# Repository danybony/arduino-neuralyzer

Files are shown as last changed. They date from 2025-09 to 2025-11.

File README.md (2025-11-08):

# Arduino-Android Neuralyzer
A Men in Black Neuralyzer made with Arduino and controlled by an Android app.

Presented at [DevFest Pescara 2025](https://devfest.gdgpescara.it/it/).

https://github.com/user-attachments/assets/2ab9053a-5b03-4355-8828-ae3a430f30dd

## 3D printing
The neuralyzer can be easily 3d printed. All the related info are in [the dedicated document](3D_model/README.md).

## Bill Of Material

- Arduino Nano 33 BLE https://store.arduino.cc/products/arduino-nano-33-ble 

- Arduino Nano Connector Carrier https://store.arduino.cc/products/nano-connector-carrier

- Modulino Pixels https://store.arduino.cc/products/modulino-pixels

- Modulino Buttons https://store.arduino.cc/products/modulino-buttons
  
- 9V PP3 battery 

- 9V PP3 battery connector https://amzn.to/47Poghs 

## Slide Deck

[Presentation here](https://docs.google.com/presentation/d/1N28yC9nN8kCC65EGHAueS5vN4FuV5YYNEZBnSAGI6ws/edit?usp=sharing)

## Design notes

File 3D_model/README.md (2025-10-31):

# Arduino-Android Neuralyzer 3D model
The 3D model for the neuralyzer is composed of the following parts, each one with the relative .stl print file:

- **Bottom enclosure**: the base of the model, contains the battery and the Arduino
- **Top enclosure**: the upper part of the model, contains the Modulino modules, and the trigger button
- **Button**: the trigger button, aligned with the central Modulino button
- **Top sphere**: the dome at the top of the model
- **Modulino beds**: internal support for the two Modulinos. They are marked with L for the LED Modulino, B for the buttons Modulino. They slide inside the top enclosure

## Print configuration

- Filament: PLA
- Layers height: 0.20 mm
- Infil: 25%
- Brim: optional
- Support: everywhere, organic. Only needed for the top enclosure.

## Asssembly

1. Place each Modulino to the relative supporting bed: the one marked with L for the LED one, B for the button one
2. Connect the two Modulinos together with their ribbon cable, making it pass through the supporting beds central hole, like in the following picture:

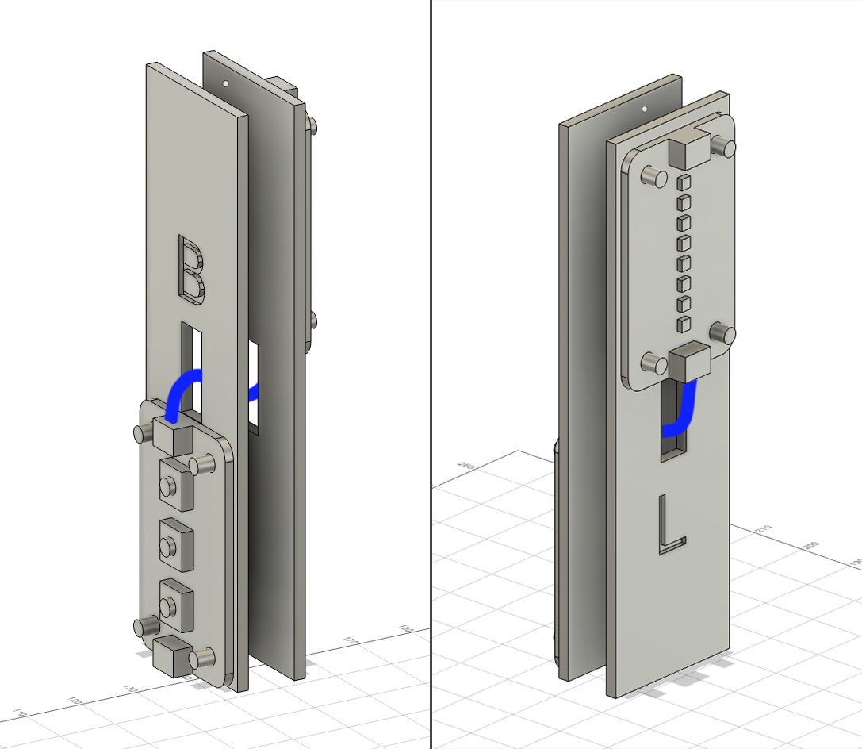
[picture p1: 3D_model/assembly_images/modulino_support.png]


3. Place the button in the top enclosure:

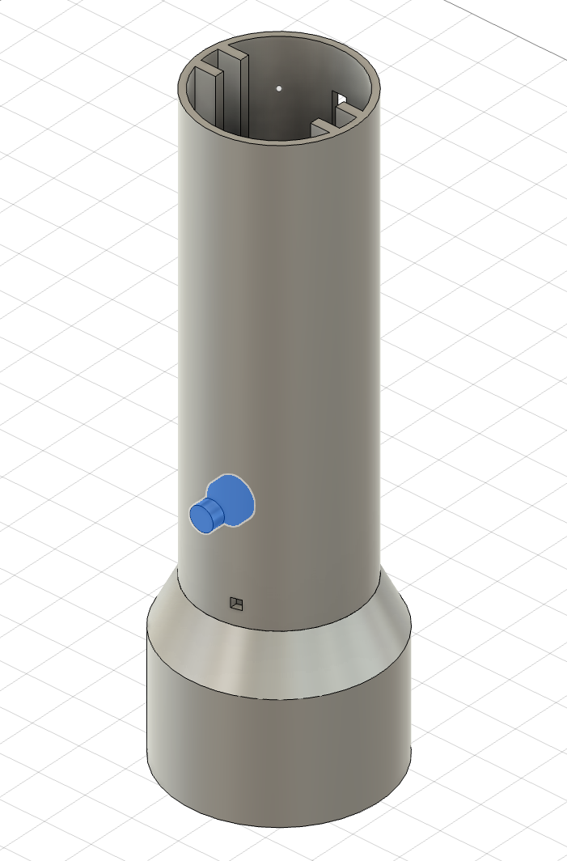
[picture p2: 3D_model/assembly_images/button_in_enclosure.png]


4. Connect an extra ribbon cable at the bottom of the buttons Modulino
5. Slide the two supporting beds inside the top enclosure, from the top

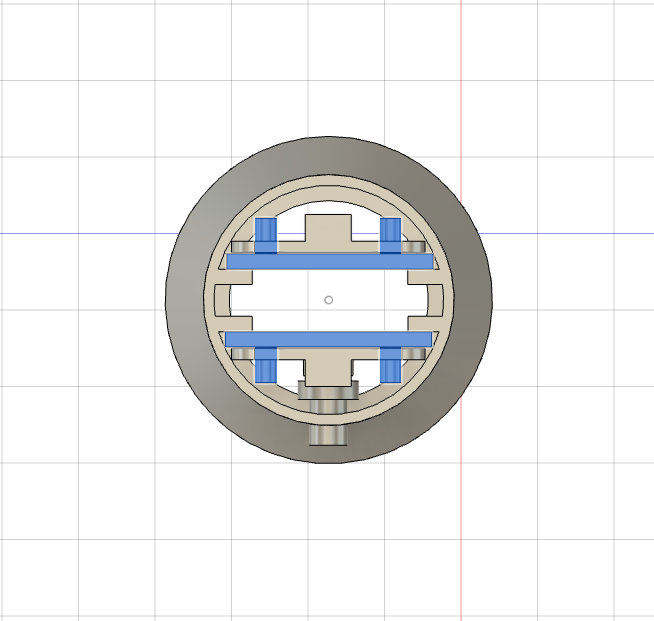
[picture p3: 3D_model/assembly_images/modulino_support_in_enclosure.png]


6. Connect the Arduino base with the ribbon cable you previously connected with the buttons Modulino, coming from the top enclosure
7. Connect the 9V battery connector cable to the GND and VIN pins in the Arduino and to the battery
8. Slide the 9V battery in the bottom enclosure with the Arduino on top

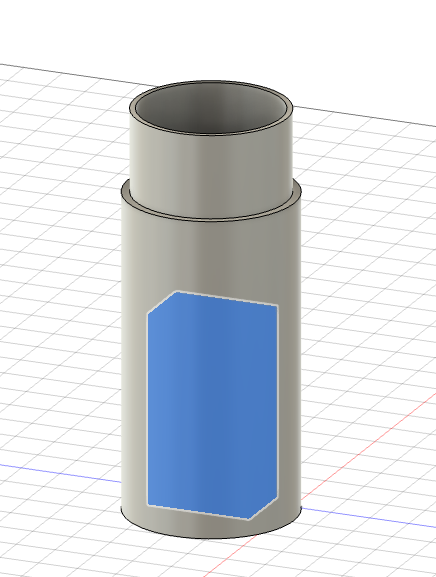
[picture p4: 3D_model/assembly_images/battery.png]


9. Slide the bottom enclosure inside the top enclosure and add the dome on top
10. Start erasing memories! 😎

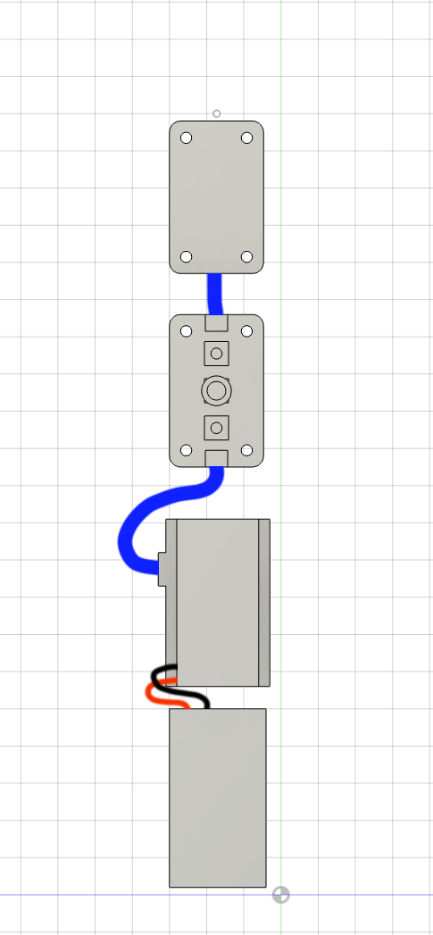
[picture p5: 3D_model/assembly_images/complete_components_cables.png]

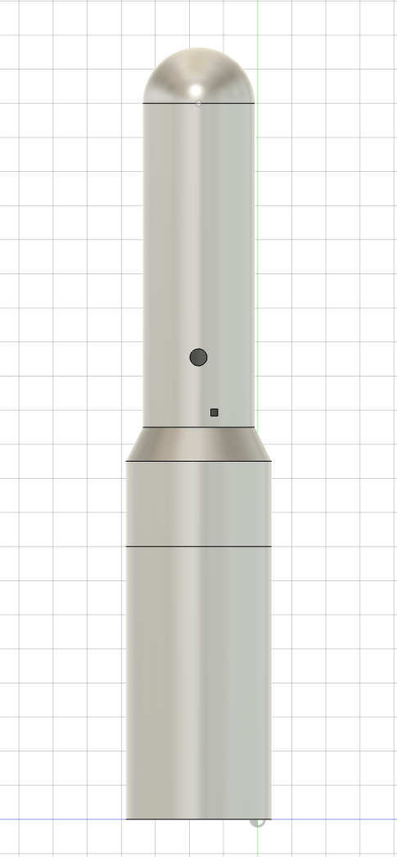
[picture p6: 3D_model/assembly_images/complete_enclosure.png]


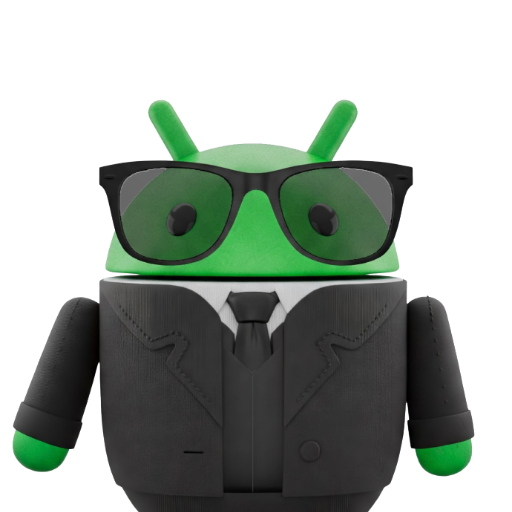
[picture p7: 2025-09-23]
Assets/play_store_512.png

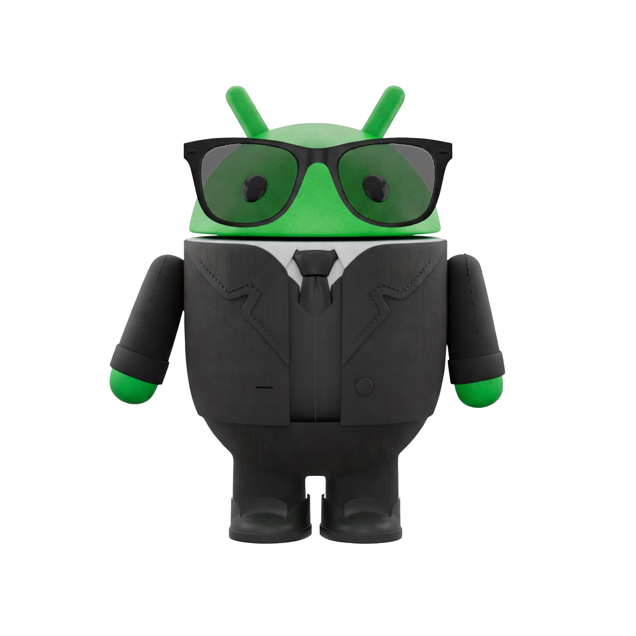
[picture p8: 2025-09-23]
Assets/men in black android.png

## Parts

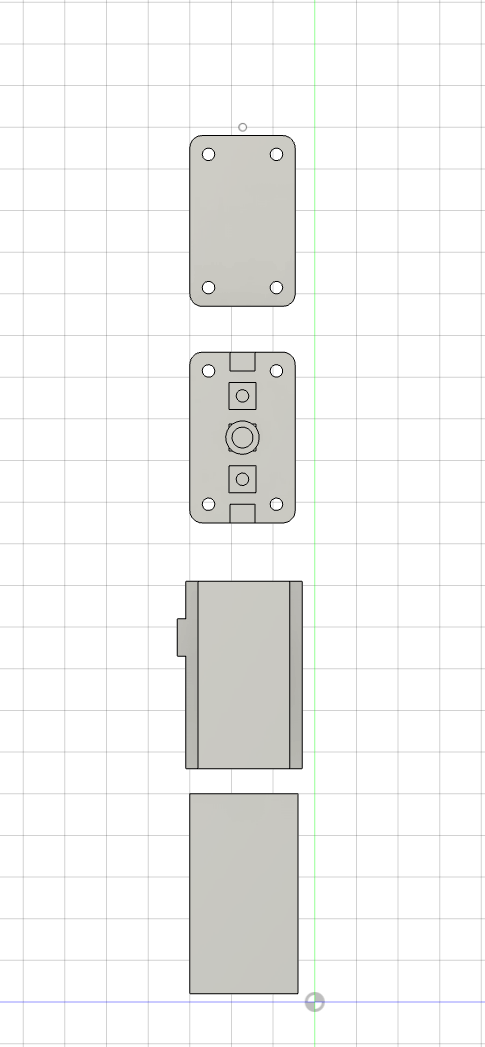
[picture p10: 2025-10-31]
3D_model/assembly_images/complete_components.png

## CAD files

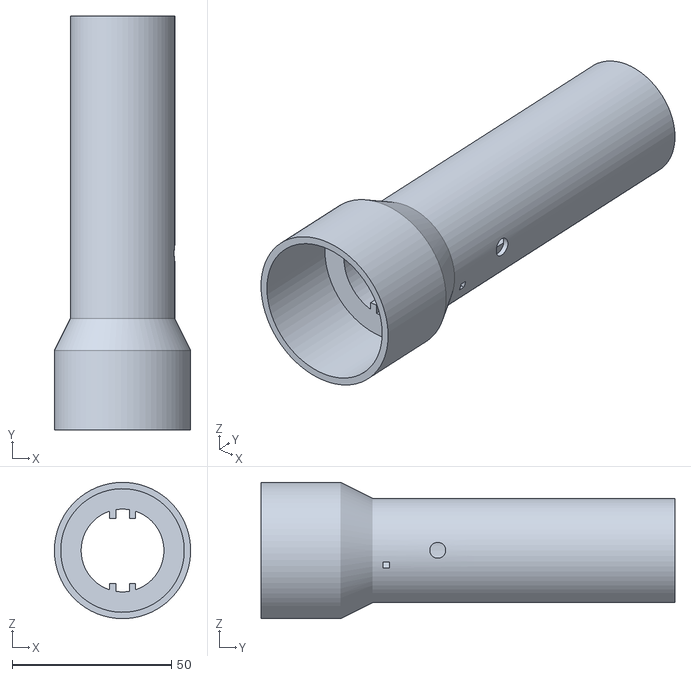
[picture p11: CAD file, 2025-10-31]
3D_model/print_files/Top enclosure 9v.stl
42.8 x 130.0 x 42.8

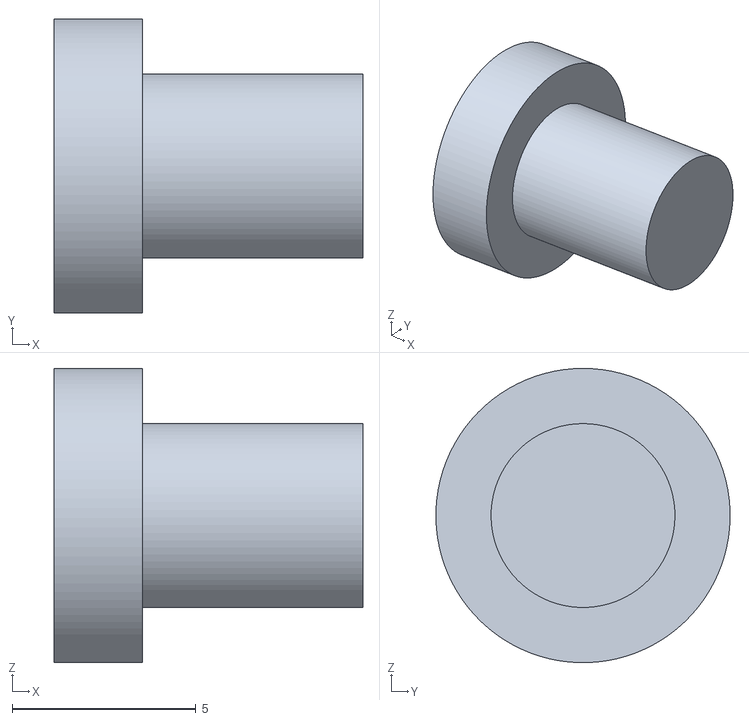
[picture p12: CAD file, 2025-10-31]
3D_model/print_files/Button.stl
8.40 x 8.00 x 8.00

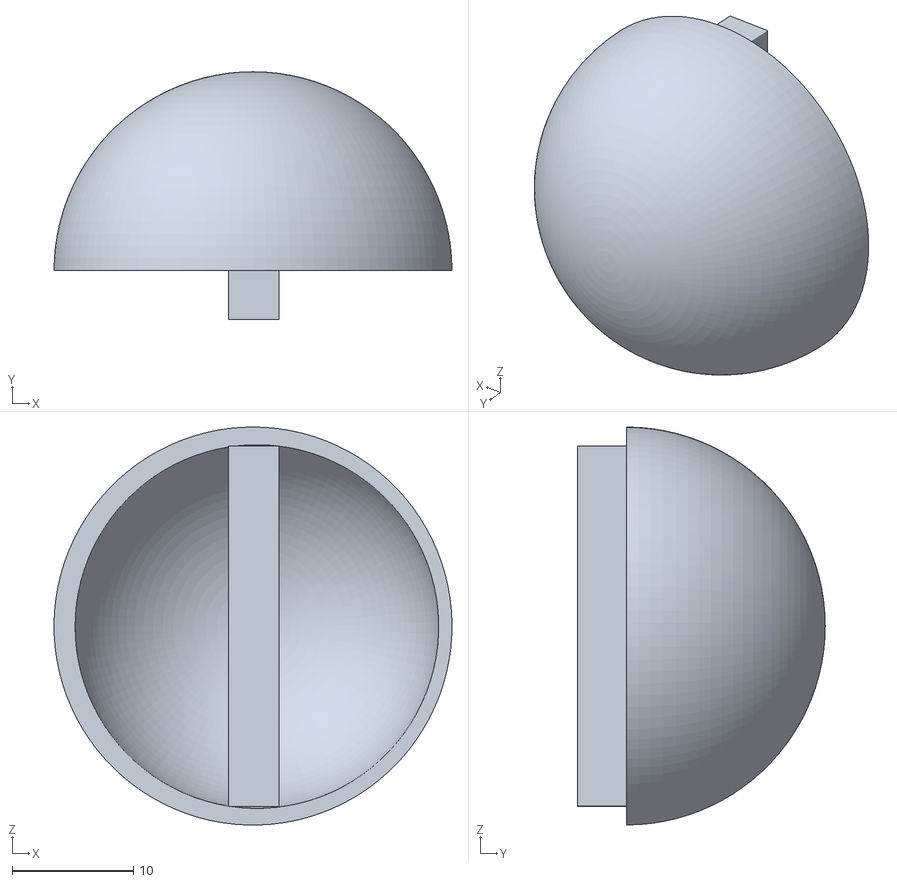
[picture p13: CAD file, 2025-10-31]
3D_model/print_files/Top dome.stl
32.8 x 20.4 x 32.8

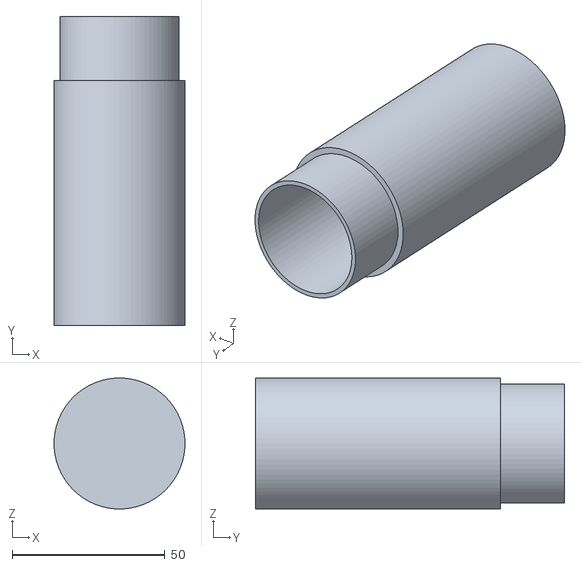
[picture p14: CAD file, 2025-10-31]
3D_model/print_files/Bottom enclosure 9v.stl
42.8 x 101.0 x 42.8

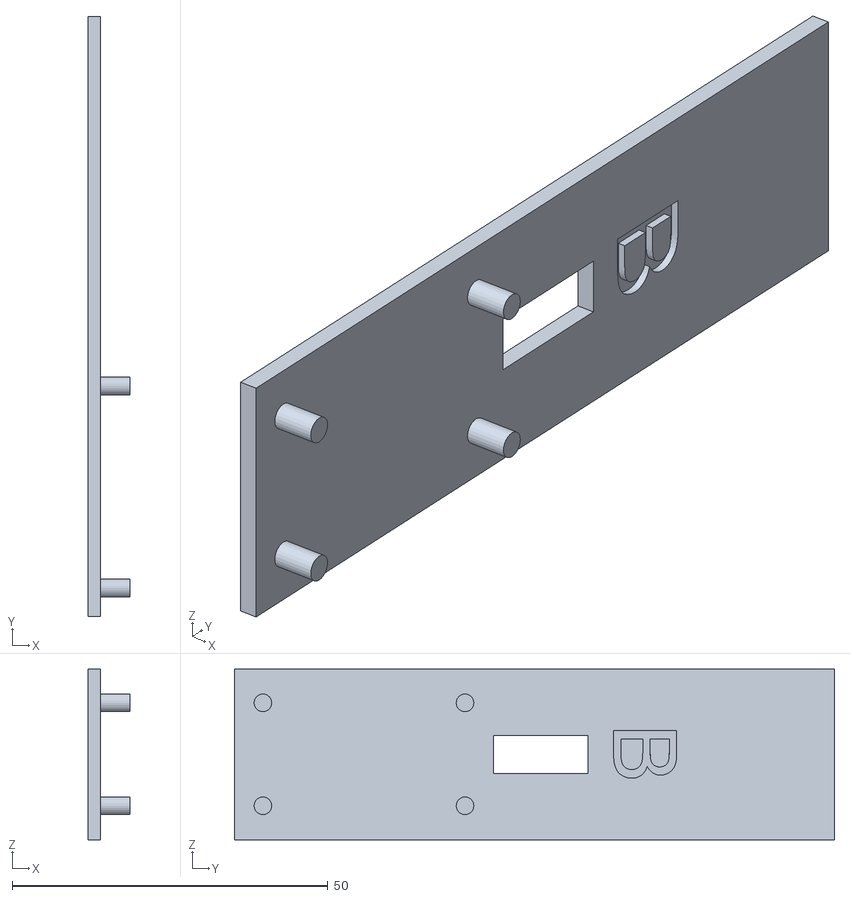
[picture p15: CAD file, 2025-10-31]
3D_model/print_files/Modulino buttons bed.stl
6.66 x 95.0 x 27.0

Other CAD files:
3D_model/print_files/Modulino leds bed.stl

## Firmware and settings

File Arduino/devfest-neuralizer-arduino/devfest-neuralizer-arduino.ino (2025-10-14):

/*
  Neuralizer - BLE Controlled Modulino LEDs

  Description:
    This sketch implements a BLE (Bluetooth Low Energy) peripheral named "devfest-neuralizer". 
    It allows an external smartphone app (BLE Central) to set RGB color and brightness. 
    When a button on the Modulino Buttons is pressed, the LEDs of Modulino Pixels light up
    according to the stored color and brightness settings. 
    Brightness levels control how many LEDs are turned on:
    0 = off, 1 = 2 LEDs, 2 = 5 LEDs, 3 = 8 LEDs.

  Hardware Required:
    - Arduino board with BLE support (e.g., Nano 33 BLE, Nano 33 BLE Sense)
    - Arduino Modulino Buttons
    - Arduino Modulino Pixels

  BLE Specifications:
    Device Name: "devfest-neuralizer"
    Service UUID: 12345678-1234-5678-1234-56789abcdef1
    Characteristics:
      - Color (3 byte, Read/Write): 12345678-1234-5678-1234-56789abcdef2
      - Brightness (1 byte, Read/Write): 12345678-1234-5678-1234-56789abcdef3
      - Active State (1 byte, Read/Notify): 12345678-1234-5678-1234-56789abcdef4

  Libraries:
    - Modulino by Arduino
    - ArduinoBLE by Arduino

  Authors:
    - Leonardo Cavagnis
*/

//TODO: Storing values in EEPROM

#include <ArduinoBLE.h>
#include <Modulino.h>

ModulinoButtons buttons;
ModulinoPixels pixels;

// --- BLE UUIDs ---
#define BASE_UUID        "12345678-1234-5678-1234-56789abcdef0"
#define SERVICE_UUID     "12345678-1234-5678-1234-56789abcdef1"
#define COLOR_UUID       "12345678-1234-5678-1234-56789abcdef2"
#define BRIGHTNESS_UUID  "12345678-1234-5678-1234-56789abcdef3"
#define ACTIVE_UUID      "12345678-1234-5678-1234-56789abcdef4"

// --- BLE Service & Characteristics ---
BLEService neuralizerService(SERVICE_UUID);
BLECharacteristic colorChar(COLOR_UUID, BLERead | BLEWrite, 3);      // RGB
BLEByteCharacteristic brightnessChar(BRIGHTNESS_UUID, BLERead | BLEWrite);
BLEByteCharacteristic activeChar(ACTIVE_UUID, BLERead | BLENotify);

uint8_t color[3] = {255, 255, 255};   // default white
uint8_t brightness = 1;               // 0=off, 1=low, 2=medium, 3=high

void setup() {
  Serial.begin(9600);

  // --- Modulino Setup ---
  Modulino.begin();
  buttons.begin();
  pixels.begin();

  for(int i = 0; i < 8; i++) {
    pixels.clear(i);
  }
  pixels.show();

  buttons.setLeds(false, false, false);

  // --- BLE Setup ---
  if (!BLE.begin()) {
    Serial.println("Failed to start BLE!");
    while (1);
  }

  BLE.setLocalName("devfest-neuralizer");
  BLE.setAdvertisedService(neuralizerService);

  // Add characteristics to service
  neuralizerService.addCharacteristic(colorChar);
  neuralizerService.addCharacteristic(brightnessChar);
  neuralizerService.addCharacteristic(activeChar);

  BLE.addService(neuralizerService);

  // Set initial values
  colorChar.writeValue(color, 3);
  brightnessChar.writeValue(brightness);
  activeChar.writeValue(0);

  BLE.advertise();
  Serial.println("BLE Neuralizer Peripheral started");
}

void loop() {
  // --- BLE: Check incoming connection ---
  BLEDevice central = BLE.central();

  // --- Buttons management ---
  bool anyPressed = false;

  if (buttons.update()) {
    if (buttons.isPressed('A') || buttons.isPressed('B') || buttons.isPressed('C')) {
      anyPressed = true;
      showPixels(color, brightness);
    } else {
      showPixels(color, 0); // Level 0 = LEDs OFF
    }

    // If BLE is connected, notify the button press
    if (central && central.connected()) {
      activeChar.writeValue(anyPressed ? 1 : 0);
    }
  }

  // --- BLE: Characteristics management if connected ---
  if (central && central.connected()) {
    // Check if color was written
    if (colorChar.written()) {
      colorChar.readValue(color, 3);
      Serial.print("Color updated: ");
      Serial.print(color[0]); Serial.print(",");
      Serial.print(color[1]); Serial.print(",");
      Serial.println(color[2]);
    }

    // Check if brightness was written
    if (brightnessChar.written()) {
      brightness = brightnessChar.value();
      Serial.print("Brightness updated: ");
      Serial.println(brightness);
    }
  }

  // Delay for stability
  delay(10);
}

// --- Function to update Pixels according to brightness ---
void showPixels(uint8_t rgb[3], uint8_t level) {
  int ledsOnStart = -1;
  int ledsOnEnd = -1;
  switch(level) {
    case 0: ledsOnStart = -1; ledsOnEnd = -1; break;
    case 1: ledsOnStart = 3; ledsOnEnd = 4; break;
    case 2: ledsOnStart = 2; ledsOnEnd = 5;  break;
    case 3: ledsOnStart = 0; ledsOnEnd = 7; break;
    default: ledsOnStart = 0; ledsOnEnd = 7; break;
  }

  // Aggiorna tutti i LED
  for(int i = 0; i < 8; i++) {
    if(i >= ledsOnStart && i <= ledsOnEnd) {
      pixels.set(i, ModulinoColor(rgb[0], rgb[1], rgb[2]), 30); // LED ON 
    } else {
      pixels.set(i, ModulinoColor(0, 0, 0), 0);                 // LED OFF
    }
  }

  pixels.show();
}

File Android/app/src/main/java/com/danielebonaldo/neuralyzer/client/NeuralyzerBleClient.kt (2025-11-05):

package com.danielebonaldo.neuralyzer.client

import android.Manifest
import android.annotation.SuppressLint
import android.bluetooth.BluetoothDevice
import android.bluetooth.BluetoothGatt
import android.bluetooth.BluetoothGattCallback
import android.bluetooth.BluetoothGattCharacteristic
import android.bluetooth.BluetoothGattDescriptor
import android.bluetooth.BluetoothManager
import android.bluetooth.BluetoothStatusCodes
import android.content.Context
import android.content.Context.BLUETOOTH_SERVICE
import android.content.pm.PackageManager
import android.graphics.Color
import android.os.Build
import android.util.Log
import androidx.annotation.IntRange
import androidx.core.app.ActivityCompat
import kotlinx.coroutines.CoroutineScope
import kotlinx.coroutines.Dispatchers
import kotlinx.coroutines.flow.MutableSharedFlow
import kotlinx.coroutines.flow.MutableStateFlow
import kotlinx.coroutines.flow.SharedFlow
import kotlinx.coroutines.flow.StateFlow
import kotlinx.coroutines.launch


private const val TAG = "NeuralyzerLedBleClient"

class NeuralyzerBleClient(private val context: Context) {

    private var mBluetoothGatt: BluetoothGatt? = null
    private val bleManager =
        context.getSystemService(BLUETOOTH_SERVICE) as BluetoothManager
    private var bluetoothDevice: BluetoothDevice? = null
    private val localScopeStatus = CoroutineScope(Dispatchers.IO)

    private val _deviceConnectionStatus = MutableStateFlow<SDeviceStatus>(SDeviceStatus.UNKNOWN)
    val deviceConnectionStatus = _deviceConnectionStatus as StateFlow<SDeviceStatus>

    private val _ledIntensity = MutableSharedFlow<Int>()
    val ledIntensity = _ledIntensity as SharedFlow<Int>

    private val _ledColor = MutableSharedFlow<Int>()
    val ledColor = _ledColor as SharedFlow<Int>

    private val _ledActive = MutableSharedFlow<Boolean>()
    val ledActive = _ledActive as SharedFlow<Boolean>

    private lateinit var mMacAddress: String

    /**
     * Connect to the Cradle Smart Light by macAddress
     *
     * @param macAddress the macAddress of the safety cushion
     */
    @SuppressLint("MissingPermission")
    fun connect(macAddress: String) {
        mMacAddress = macAddress
        if (!hasConnectPermission()) {
            return
        }

        bleManager.adapter.getRemoteDevice(macAddress)?.let {
            bluetoothDevice = it
            mBluetoothGatt = bluetoothDevice?.connectGatt(context, false, gattCallback)
        } ?: run {
            throw Exception("Bluetooth device not found, please scan first")
        }
    }

    /**
     * Disconnect from the safety cushion
     */
    @SuppressLint("MissingPermission")
    fun disconnect() {
        if (!hasConnectPermission()) {
            return
        }
        mBluetoothGatt?.disconnect()
    }

    /**
     * Turn ON / OFF the LED
     *
     * @param value ESwitch.ON select on/off status
     */
    fun setLEDStatus(value: ESwitch): Boolean? {
        val service = mBluetoothGatt?.getService(NeuralyzerLedUUID.NeuralyzerLightService.uuid)
        val characteristic =
            service?.getCharacteristic(NeuralyzerLedUUID.NeuralyzerLightService.LEDColor.uuid)

        val payload = byteArrayOf(value.value.toByte())
        return sendCommand(characteristic, payload)
    }

    /**
     * Change LED Color by using RGB value
     *
     * @param red Red Color
     * @param green Green Color
     * @param blue Blue Color
     */
    fun setLEDColor(
        @IntRange(from = 0L, to = 255L) red: Int,
        @IntRange(from = 0L, to = 255L) green: Int,
        @IntRange(from = 0L, to = 255L) blue: Int
    ): Boolean? {
        val service = mBluetoothGatt?.getService(NeuralyzerLedUUID.NeuralyzerLightService.uuid)
        val characteristic =
            service?.getCharacteristic(NeuralyzerLedUUID.NeuralyzerLightService.LEDColor.uuid)

        val payload = byteArrayOf(red.toByte(), green.toByte(), blue.toByte())
        return sendCommand(characteristic, payload)
    }

    /**
     * Sets the LED effect for a Bluetooth-connected LED device.
     *
     * Communicates with a Bluetooth LE (Low Energy) device to set the LED effect based on the specified effect index. The effect index should be within the range of 0 to 255.
     *
     * @param effectIndex An integer representing the LED effect index, constrained within the range 0 to 2 inclusive.
     * @return Returns a Boolean indicating the success of the operation. `true` if the command is successfully sent, `false` if the BluetoothGatt service or characteristic is null, or if the command fails. Returns `null` if an exception occurs.
     */
    fun setLEDIntensity(@IntRange(from = 0L, to = 3) effectIndex: Int): Boolean {
        val service = mBluetoothGatt?.getService(NeuralyzerLedUUID.NeuralyzerLightService.uuid)
        val characteristic = service?.getCharacteristic(NeuralyzerLedUUID.NeuralyzerLightService.LEDIntensity.uuid)

        val payload = byteArrayOf(effectIndex.toByte())
        return sendCommand(characteristic, payload)
    }

    @SuppressLint("MissingPermission")
    private fun sendCommand(
        characteristic: BluetoothGattCharacteristic?,
        payload: ByteArray
    ): Boolean {
        if (characteristic == null) {
            Log.d(TAG, "null characteristic on sendCommand")
            return false
        }
        if (Build.VERSION.SDK_INT >= Build.VERSION_CODES.TIRAMISU) {
            val result = mBluetoothGatt?.writeCharacteristic(
                characteristic,
                payload,
                BluetoothGattCharacteristic.WRITE_TYPE_DEFAULT
            )

            val res = when (result) {
                BluetoothStatusCodes.SUCCESS -> true
                else -> {
                    Log.d(TAG, "sendCommand: Error with result $result")
                    false
                }
            }
            return res
        } else {
            characteristic.value = payload
            return mBluetoothGatt?.writeCharacteristic(characteristic) == true
        }
    }

    @SuppressLint("MissingPermission")
    fun readLEDColor(): Boolean? {
        val service = mBluetoothGatt?.getService(NeuralyzerLedUUID.NeuralyzerLightService.uuid)
        val characteristic =
            service?.getCharacteristic(NeuralyzerLedUUID.NeuralyzerLightService.LEDColor.uuid)

        return mBluetoothGatt?.readCharacteristic(characteristic)
    }

    @SuppressLint("MissingPermission")
    fun readLEDIntensity(): Boolean? {
        val service = mBluetoothGatt?.getService(NeuralyzerLedUUID.NeuralyzerLightService.uuid)
        val characteristic =
            service?.getCharacteristic(NeuralyzerLedUUID.NeuralyzerLightService.LEDIntensity.uuid)

        return mBluetoothGatt?.readCharacteristic(characteristic)
    }
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

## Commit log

2025-09-23 adding Arduino sketch
2025-10-13 Center turned on LEDs
2025-10-16 Automatically connect and read caracteristics on device selected
2025-10-31 Add 3d printing files and update readme
    [Bottom enclosure 9v.stl, Button.stl, Modulino buttons bed.stl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]
2025-11-05 Enable BLE notifications and show in UI when HW button pressed
2025-11-06 Make DeviceScreen adaptive
